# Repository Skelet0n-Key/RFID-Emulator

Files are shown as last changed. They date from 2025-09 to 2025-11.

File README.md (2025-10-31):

# Project Overview

**Introduction**

The standard PN532 is widely available and cheap. Manufacturers prevent custom UIDs from being emulated. When the 532 is put into target mode, the first byte of the UID will always be 0x08 (or 0x88 with some models). While there are ways to get around this security feature, it is difficult to implement in an embedded system, unreliable, and requires perfect timing (read more about it [here](https://www.mankier.com/1/nfc-emulate-uid)). The other solution is trivially easy to implement. Rather than go with the true emulation method, we picked up a [lab401 sector 0 programmable card](https://lab401.com/collections/all-products/products/mifare-compatible-1k-direct-write-uid). This method absolves adafruit of all legal liability, which is exactly the reason that firmware feature implementing a hardware protocol requirement (prepending a 0x08 byte) exists. Conveniently, this makes our design more discreet. 

**Challenges and Solutions**

- We wanted a controlled environment to test our project's functionality and so that's what we did. We made an RFID lock with an arduino uno and MFRC-522 module (code found [here](RFID_lock/RFID_lock.ino)). The lock came with it's own problems. It took a while to find out what was going on, but we weren't getting any response from our MFRC-522 because it wasn't an official module. We needed to slow down communication to our module and connect it to 5V even though 3.3V was printed on the PCB. *Note: we labeled it 3.3V-3.3V in the wiring diagram*
- The original idea for this project was to have the PN532 emulate the copied UID itself. Unfortunately, due to security concerns (😒) the PN532 prepends a 0x08 byte when it sends its UID. So calling the command to send a specified UID like: 0x0000BEEF, would send: 0x080000BE. Luckily, you can just write a non-modified UID to a card. So this is what we ended up pivoting to as you read above.

**Timeline**

- Test lock finished (9/26/25)
- Basic read functions implemented on PN532 (10/7/25)
- Emulating function implemented, it is discovered that an 0x08 is prepended to every emulation (10/16/25)
- Writing function finished (10/23/25)
- Functional prototype finished (10/27/25)
- Rev1 finsihed with screen displaying selectable UIDs to write. UIDs saved in memory ()
- NFC compatibility added ()
- wifi de-auther added ()
- 125kHz module added ()

**Testing and Results**

# Project Capabilities

# Hardware Components

 - Raspberry Pi Pico 2 W
 - Adafruit PN532
 - *Arduino UNO
 - *RFID-MFRC522 module

*Necessary for RFID test lock

# Software Dependencies

 - [micropython .UF2 for pi pico 2 W](https://www.raspberrypi.com/documentation/microcontrollers/micropython.html)
 - [NFC PN532 SPI library](https://github.com/Carglglz/NFC_PN532_SPI?tab=readme-ov-file)
 - *[MFRC library](https://docs.arduino.cc/libraries/mfrc522)

*Necessary for RFID test lock

# Implementation

## Wiring Diagrams and Information

**Emulator**
*Diagram Here*

| RPI Pico 2 W | Adafruit PN532 Breakout |
|:---|:---|
| 3V3 (3.3V) | Vcc / 3.3V |
| GND | GND |
| GP16 (SPI0 MISO) | MISO (SSO / SO) |
| GP17 (CS / CHIP_SELECT | SS (active low) |
| GP18 (SPI0 SCK) | SCK |
| GP19 (SPI0 MOSI) | MOSI (SDA) |
| (optional) GP15 | IRQ |
| (optional) GP20 | RSTO / RST |

**RFID Lock**
*Diagram Here*

| Arduino Uno | MFRC-522 |
|:----|:----|
| 3.3V | 3.3V |
| GND | GND |
| D9 | RST |
| D10 | SDA |
| D11 | MOSI |
| D12 | MISO |
| D13 | SCK |
| N/A | IRQ |

We also used two indicator LEDs on D2 and D4 so we didn't have to look at the terminal everytime to see if access was granted / denied. 

## CAD Files

We used a few prints to bring this project together and give it a more prolished look. You can find them [here]()
(link)

# Acknowledgements
We used Carglglz's [driver](https://github.com/Carglglz/NFC_PN532_SPI) to control the basic functions of the PN532, such as initialization and reading mifare classics.

We added functionality to that driver using the principles from the [Adafruit PN532 driver](https://github.com/adafruit/Adafruit-PN532/blob/master/Adafruit_PN532.cpp) to write data to a programmable card, following mifare classic protocol.

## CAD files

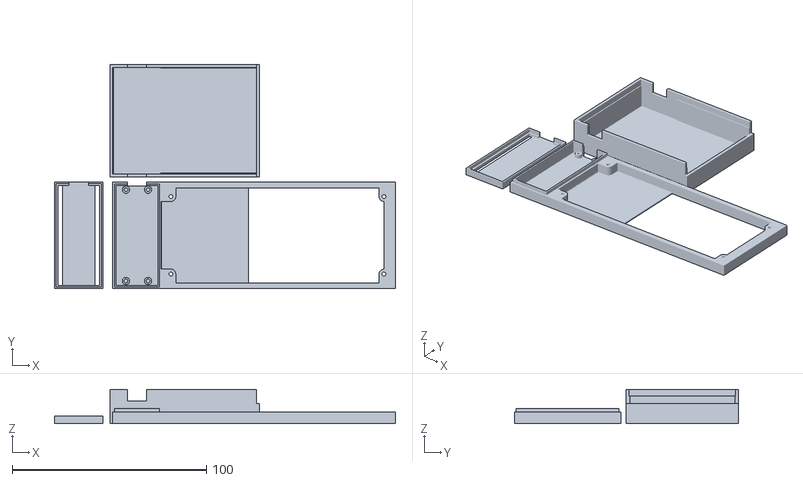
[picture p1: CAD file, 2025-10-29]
Cad_files/case v8.stl
175.6 x 115.6 x 17.7

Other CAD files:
Cad_files/case v8.f3d

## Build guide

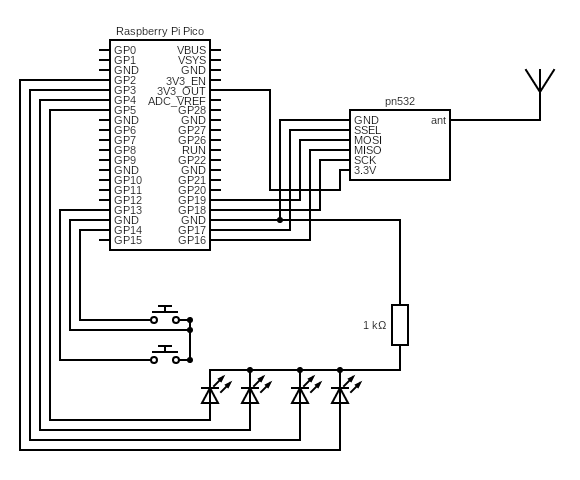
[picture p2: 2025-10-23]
Wiring_diagrams/circuit.png

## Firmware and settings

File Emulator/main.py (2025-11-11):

from machine import Pin, SPI, I2C
import NFC_PN532 as nfc
from ssd1306 import SSD1306_I2C
import time
import ujson
import os

# ==== I2C setup ====
i2c = I2C(1, scl=Pin(3), sda=Pin(2))  # I2C1 uses GP2 (SDA) and GP3 (SCL)

# ==== OLED setup ====
WIDTH = 128
HEIGHT = 32  # most 0.91" displays are 128x32
oled = SSD1306_I2C(WIDTH, HEIGHT, i2c)

# --- NFC/SPI Setup ---
spi = SPI(0,
          baudrate=1152000,
          polarity=0,
          phase=0,
          bits=8,
          firstbit=SPI.MSB,
          sck=Pin(18),
          mosi=Pin(19),
          miso=Pin(16))

cs = Pin(17, Pin.OUT)
cs.value(1)
rst = Pin(20, Pin.OUT)
rst.value(1)
# IRQ pin is not used in this library's polling mode
# irq = Pin(15, Pin.IN) 
irq = None # Set to None
# Initialize GPIO pins for the buttons.
# We are using internal pull-ups, so the buttons should be wired
# to connect the pin to ground when pressed.
up_button = Pin(14, Pin.IN, Pin.PULL_UP)
sel_button = Pin(13, Pin.IN, Pin.PULL_UP)
down_button = Pin(5, Pin.IN, Pin.PULL_UP)


# menus
mainMenu = [" ", "Mifare Classic", "NTAG", "Clear Saved", " "]
mifareMenu = [" ", "..", "Mifare Read", "Write current", "Save current", "Load from saved", " "]
ntagMenu = [" ", "..", "NTAG read", "Write current", "Save current", "Load from saved", " "]

# saved data
MIFARE_FILE = "saved_mifare.json"
NTAG_FILE = "saved_ntag.json"
savedUIDsMifare = []
savedUIDsNTAG = []
saved_block_0 = None

# --- PN532 Initialization ---
print("Initializing PN532...")
pn532 = nfc.PN532(spi, cs, rst, irq)
ic, ver, rev, support = pn532.get_firmware_version()
print('Found PN532 with firmware version: {}.{}'.format(ver, rev))
pn532.SAM_configuration()

# initialize screen and menu
currentMenu = mainMenu
currentOptionIndex = 1
driverSelection = None

def calculate_bcc(uid_bytes):
    """
    Calculates the BCC (XOR checksum) for a 4-byte MIFARE UID.
    """
    if len(uid_bytes) != 4:
        raise ValueError("UID must be 4 bytes long")
    bcc = 0
    for byte in uid_bytes:
        bcc ^= byte
    return bcc


def read_source_card_data(dev, timeout_ms=5000):
    """
    Waits for a source card, authenticates block 0, validates its BCC, 
    and reads the 16-byte block.
    Returns the 16 bytes of block 0, or None if it fails.
    """
    print('Waiting for SOURCE card...')
    oled_print("Waiting for SOURCE card...", clear=True)
    print('Present the card you want to CLONE.')
    start = time.ticks_ms()
    uid = None
    while time.ticks_diff(time.ticks_ms(), start) < timeout_ms:
        # Check for a card
        uid = dev.read_passive_target(timeout=100)
        if uid is not None:
            # Card found, break out of the loop
            break
        time.sleep(0.1)

    if not uid:
        print('CARD NOT FOUND')
        oled_print("CARD NOT FOUND", clear=True)
        return None
        
    uid_string = "".join(["{:02X}".format(i) for i in uid])
    print(f"Found source card with UID: {uid_string}")
    oled_print(f"Found:\n{uid_string}", clear=True)

    # Authenticate block 0 (or any block in sector 0) to read it.
    # We'll try a common default key, KEY_DEFAULT_B (all 0xFFs)
    print("Trying to authenticate with default key FF FF FF FF FF FF...")
    oled_print("Authenticating\nsource card...", clear=False)
    if not dev.mifare_classic_authenticate_block(uid, 0, nfc.MIFARE_CMD_AUTH_B, nfc.KEY_DEFAULT_B):
        print("Failed to authenticate block 0 with default key.")
        print("Note: Card must use the default key FF FF FF FF FF FF for this to work.")
        oled_print("Authentication\nfailed!", clear=True)
        return None
    
    print("Authentication successful.")
    oled_print("Authentication\nsuccessful!", clear=True)
    
    # Read block 0
    block0_data = dev.mifare_classic_read_block(0)
    
    if not block0_data:
        print("Failed to read block 0.")
        oled_print("Read Block 0\nfailed!", clear=True)
        time.sleep(1)
        return None

    print(f"Successfully read Block 0: {[hex(b) for b in block0_data]}")
    oled_print("Read Block 0\nsuccessful!", clear=True)
    time.sleep(1)

    # --- BCC SAFETY CHECK ---
    print("Validating source card BCC...")
    oled_print("Validating\nsource card BCC...", clear=True)
    card_uid_part = block0_data[0:4]
    card_bcc_part = block0_data[4]
    
    calculated_bcc = calculate_bcc(card_uid_part)
    
    if card_bcc_part == calculated_bcc:
        print(f"BCC is valid! (Read: 0x{card_bcc_part:02X}, Calculated: 0x{calculated_bcc:02X})")
        oled_print("BCC VALIDATION\nSUCCESS!", clear=True)
        time.sleep(0.5)
        oled_print("Block 0 Data:\n" + "".join(["{:02X}".format(b) for b in block0_data]), clear=True)
        time.sleep(3)
        return block0_data
    else:
        print("--- !!! BCC VALIDATION FAILED !!! ---")
        oled_print("!!! BCC VALIDATION\nFAILED !!!", clear=True)
        print(f"Read UID: {[hex(b) for b in card_uid_part]}")
        print(f"Read BCC: 0x{card_bcc_part:02X}")
        print(f"Calculated BCC: 0x{calculated_bcc:02X}")
        print("This card may be damaged or non-standard. Aborting clone to prevent bricking.")
        time.sleep(0.5)
        return None
    # --- END OF BCC CHECK ---


def write_data_to_clone(dev, block_data, timeout_ms=10000):
    """
    Waits for a programmable card and writes the saved block 0 data to it.
    This requires a special UID-modifiable card.
    """
    print("Waiting for TARGET card...")
    oled_print("Waiting for TARGET card...", clear=True)
    print("Present your UID-MODIFIABLE (magic) card.")

    # Wait for a target card to appear
    start_wait = time.ticks_ms()
    target_uid = None
    while time.ticks_diff(time.ticks_ms(), start_wait) < timeout_ms:
        target_uid = dev.read_passive_target(timeout=100)
        if target_uid is not None:
            break
        time.sleep(0.1)

    if not target_uid:
        print("No target card found to write to. Aborting.")
        oled_print("No target card found.\nAborting.", clear=True)
        return

    target_uid_string = "".join(["{:02X}".format(i) for i in target_uid])
    print(f"Found target card with UID: {target_uid_string}")
    oled_print(f"Found target card:\n{target_uid_string}", clear=True)

    # For "Gen2" or "lab 401" cards, we can try a normal authentication
    # and then a standard write command to block 0.
    
    print("Attempting to authenticate target card...")
    # authenticate with the card's current key.
    # For a blank/new magic card, this is often the default key.
    if not dev.mifare_classic_authenticate_block(target_uid, 0, nfc.MIFARE_CMD_AUTH_B, nfc.KEY_DEFAULT_B):
        print("Failed to authenticate target card with default key.")
        oled_print("Authentication\nfailed!", clear=True)
        time.sleep(1.5)
        return
        
    print("Target card authenticated. Attempting to write to Block 0...")
    oled_print("Writing to\nBlock 0...", clear=True)
    
    # Now, try to write the saved block 0 data
    if dev.mifare_classic_write_block(0, block_data):
        print("SUCCESS! Block 0 written.")
        oled_print("Write SUCCESS!", clear=True)
        print(f"Wrote data: {[hex(b) for b in block_data]}")
        oled_print(f"Wrote data:\n{''.join(['{:02X}'.format(b) for b in block_data])}", clear=True)
        time.sleep(1.5)
        return
    else:
        print("Error: Failed to write to block 0.")
        oled_print("Write FAILED!", clear=True)
        time.sleep(1.5) 
        return


def driver_select(selection):
    global saved_block_0
    if selection == 0: #scan mifare classic
        scanned_data = read_source_card_data(pn532)
    
        if scanned_data:
            saved_block_0 = scanned_data # Save the 16-byte block
            print("Block 0 data saved.")
            oled_print("Scan successful!\nData saved.", clear=True)
            time.sleep(1.5)
        else:
            print("Scan failed. No data was saved.")
            oled_print("Scan failed.\nNo data saved.", clear=True)  
            time.sleep(1.5)

    elif selection == 1:#write mifare classic
        print("Writing saved Block 0 data to target card...")
        if saved_block_0 is None:
            print("Error: No data has been saved from a source card.")
            oled_print("No saved data!\nScan first.", clear=True)
            time.sleep(1.5)
        else:
            data_string = "".join(["{:02X}".format(i) for i in saved_block_0])
            print(f"Writing data: {data_string}")
            oled_print(f"Writing data:\n{data_string}", clear=True)
            write_data_to_clone(pn532, saved_block_0)

    elif selection == 2: #save current mifare classic TODO
        oled_print("Saving current\nMIFARE UID...", clear=True)
        time.sleep(0.5)
        savedUIDsMifare.append(saved_block_0)
        save_list_to_file(savedUIDsMifare, MIFARE_FILE) 

    elif selection== 3: #display saved mifare classic uids TODO
        oled_print("Loading saved\nMIFARE UIDs...", clear=True)
        time.sleep(0.5)
        savedUIDsMifare = load_list_from_file(MIFARE_FILE)
        for index, data in enumerate(savedUIDsMifare):
            data_string = "".join(["{:02X}".format(b) for b in data])
            print(f"{index + 1}: {data_string}")
            oled_print(f"{index + 1}: {data_string}")

    elif selection == 4: 
        oled_print("NTAG read not\nimplemented", clear=True)
        time.sleep(1.5)

        
    elif selection == 5: 
        oled_print("NTAG write not\nimplemented", clear=True)
        time.sleep(1.5)

    elif selection == 6: 
        oled_print("Save current to\nNTAG list not\nimplemented", clear=True)
        time.sleep(1.5)

    elif selection == 7: 
        oled_print("Display saved\nNTAG UIDs not\nimplemented", clear=True)
        time.sleep(1.5)

    else: pass  # no action

# --- Save function ---
def save_list_to_file(data_list, filename):
    try:
        with open(filename, "w") as f:
            ujson.dump(data_list, f)
        print(f"Saved {len(data_list)} items to {filename}")
        oled_print(f"Saved {len(data_list)} items", clear=True)
    except Exception as e:
        print("Error saving file:", e)
        oled_print("Error saving file", clear=True)
    
    return

# --- Load function ---
def load_list_from_file(filename):
    try:
        with open(filename, "r") as f:
            data = ujson.load(f)
        print(f"Loaded {len(data)} items from {filename}")
        return data
    except Exception as e:
        print("Error loading file:", e)
        oled_print("Error loading file", clear=True)
        return []
    
# --- Clear saved function ---    
def clear_saved_list(list_variable, filename):
    # Clear the in-memory list
    list_variable.clear()
    
    # Overwrite the JSON file with an empty list
    try:
        with open(filename, "w") as f:
            ujson.dump([], f)
        print(f"Cleared {filename} and emptied the list.")
        oled_print(f"Cleared saved\nitems!", clear=True)
    except Exception as e:
        print("Error clearing saved file:", e)
        oled_print("Error clearing\nsaved items!", clear=True)

def oled_print(*args, sep=" ", end="\n", clear=True):
    """
    Works like Python's print(), but writes to the OLED display.
    Example: oled_print("Hello", 123)
    """
    text = sep.join(str(a) for a in args) + end

    if clear:
        oled.fill(0)  # clear screen

    # split into lines and display
    lines = text.splitlines()
    y = 0
    for line in lines:
        if y > HEIGHT - 8:
            break  # stop if screen full
        oled.text(line[:21], 0, y)  # each char ≈6px wide → fits ~21 chars
        y += 8

    oled.show()

def printMenu(menu, index):
    # Clamp the index inside valid range
    if index <= 0:
        index = 1
    if index >= len(menu) - 1:
        index = len(menu) - 2

    ln1 = menu[index - 1]
    ln2 = menu[index]
    ln3 = menu[index + 1]

    text = f"{ln1}\n>{ln2}\n{ln3}"
    oled_print(text, clear=True)

    return index

# initialize
currentMenu = mainMenu
currentOptionIndex = 1
driverSelection = None

printMenu(currentMenu, currentOptionIndex)

while True:

    if up_button.value() == 0:  # up
        time.sleep(0.2)  # Debounce delay
        if currentOptionIndex > 1:
            currentOptionIndex -= 1
        currentOptionIndex = printMenu(currentMenu, currentOptionIndex)

    elif down_button.value() == 0:  # down
        time.sleep(0.2)  # Debounce delay
        if currentOptionIndex < len(currentMenu) - 2:
            currentOptionIndex += 1
        currentOptionIndex = printMenu(currentMenu, currentOptionIndex)

    elif sel_button.value() == 0:  # select
        time.sleep(0.2)  # Debounce delay
        if currentMenu == mainMenu:
            if currentOptionIndex == 1:  # Mifare Classic
                currentMenu = mifareMenu
                currentOptionIndex = 2
            elif currentOptionIndex == 2:  # NTAG
                currentMenu = ntagMenu
                currentOptionIndex = 2
            elif currentOptionIndex == 3:  # Clear Saved
                clear_saved_list(savedUIDsMifare, MIFARE_FILE)
                clear_saved_list(savedUIDsNTAG, NTAG_FILE)
            currentOptionIndex = printMenu(currentMenu, currentOptionIndex)

        elif currentMenu == mifareMenu:
            if currentOptionIndex == 1:  # go back
                currentMenu = mainMenu
                currentOptionIndex = 1
                driverSelection = None
            elif currentOptionIndex == 2:
                driverSelection = 0
            elif currentOptionIndex == 3:
                driverSelection = 1
            elif currentOptionIndex == 4:
                driverSelection = 2
            elif currentOptionIndex == 5:
                driverSelection = 3
            if driverSelection is not None:
                driver_select(driverSelection)
                driverSelection = None
            currentOptionIndex = printMenu(currentMenu, currentOptionIndex)

        elif currentMenu == ntagMenu:
            if currentOptionIndex == 1: #go back
                currentMenu = mainMenu
                currentOptionIndex = 1
                driverSelection = None
            elif currentOptionIndex == 2:
                driverSelection = 4
            elif currentOptionIndex == 3:
                driverSelection = 5
            elif currentOptionIndex == 4:
                driverSelection = 6
            elif currentOptionIndex == 5:
                driverSelection = 7
            if driverSelection is not None:
                driver_select(driverSelection)
                driverSelection = None
            currentOptionIndex = printMenu(currentMenu, currentOptionIndex)

    else:
        # invalid key
        pass

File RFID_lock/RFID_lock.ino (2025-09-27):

// ** REFER TO THE README AT https://github.com/megabyte512/RFID-Emulator FOR WIRING INSTRUCTIONS **

#include <MFRC522.h>
#include <SPI.h>

#define SS_PIN 10
#define RST_PIN 9

MFRC522 RFID_lock(SS_PIN, RST_PIN);
int GREEN_LED_PIN = 2;
int RED_LED_PIN = 4;

void handleSerialCommands();
void addCardMode();
void removeCardMode();
void checkForCard();
void listAuthorizedCards();
void clearAllCards();
String getCardUID();
bool isCardAuthorized(String cardUID);
bool removeCard(String cardUID);

String authorizedCards[10];
int cardCount = 0;


void setup() {
  Serial.begin(9600);
  SPI.begin();
  SPI.setClockDivider(SPI_CLOCK_DIV128); // Our specific clone fix :(
  RFID_lock.PCD_Init();
  pinMode(GREEN_LED_PIN, OUTPUT);
  pinMode(RED_LED_PIN, OUTPUT);

  Serial.println("***RFID Access Control System***");
  Serial.println("- ADD: Add a new card");
  Serial.println("- LIST: Show all authorized cards");
  Serial.println("- CLEAR: Remove all cards");
  Serial.println("- REMOVE: Remove specific card");
  Serial.println();
}



void loop() {
  handleSerialCommands();
  checkForCard();
  delay(100);
}


void handleSerialCommands() {
  if (Serial.available()) {
    String command = Serial.readStringUntil('\n');
    command.trim();
    command.toUpperCase();
    
    if (command == "ADD") {
      addCardMode();
    }
    else if (command == "LIST") {
      listAuthorizedCards();
    }
    else if (command == "CLEAR") {
      clearAllCards();
    }
    else if (command == "REMOVE") {
      removeCardMode();
    }
    else {
      Serial.println("Unknown command: " + command);
    }
  }
}


void addCardMode() {
  if (cardCount >= 10) {
    Serial.println("Maximum cards reached (10)");
    return;
  }
  
  Serial.println("Listening for card...");
  
  unsigned long timeout = millis() + 10000;  // 10 second timeout
  
  while (millis() < timeout) {
    // Check for card
    if (RFID_lock.PICC_IsNewCardPresent() && RFID_lock.PICC_ReadCardSerial()) {
      String newCardUID = getCardUID();
      
      // Check if card already exists
      if (isCardAuthorized(newCardUID)) {
        Serial.println("Card already in authorized list: " + newCardUID);
      } else {
        // Add new card
        authorizedCards[cardCount] = newCardUID;
        cardCount++;
        Serial.println("Card added successfully: " + newCardUID);
        Serial.println("Total authorized cards: " + String(cardCount));
      }
      return;
    }
  }
  
  Serial.println("Add timeout - no card presented");
}


void removeCardMode() {
  if (cardCount == 0) {
    Serial.println("No cards to remove");
    return;
  }
  
  Serial.println("Listening for card to remove...");
  
  unsigned long timeout = millis() + 10000;
    while (millis() < timeout) {
      if (RFID_lock.PICC_IsNewCardPresent() && RFID_lock.PICC_ReadCardSerial()) {
        String cardUID = getCardUID();
      
        if (removeCard(cardUID)) {
          Serial.println("Card removed: " + cardUID);
          Serial.println("Total authorized cards: " + String(cardCount));
        } else {
          Serial.println("Card not found in authorized list: " + cardUID);
        }
        return;
      }
    }
  Serial.println("Remove timeout - no card presented");
}


void checkForCard() {
  if (RFID_lock.PICC_IsNewCardPresent() && RFID_lock.PICC_ReadCardSerial()) {
    String cardUID = getCardUID();
    
    if (isCardAuthorized(cardUID)) {
      Serial.println("ACCESS GRANTED: " + cardUID);
      digitalWrite(GREEN_LED_PIN, 1);
      delay(1000);
      digitalWrite(GREEN_LED_PIN, 0);
    } else {
      Serial.println("ACCESS DENIED: " + cardUID);
      digitalWrite(RED_LED_PIN, 1);
      delay(1000);
      digitalWrite(RED_LED_PIN, 0);
    }
    return;
  }
}


String getCardUID() {
  String content = "";
  for (byte i = 0; i < RFID_lock.uid.size; i++) {
    content.concat(String(RFID_lock.uid.uidByte[i] < 16 ? "0" : ""));
    content.concat(String(RFID_lock.uid.uidByte[i], HEX));
  }
  content.toUpperCase();
  return content;
}


bool isCardAuthorized(String cardUID) {
  for (int i = 0; i < cardCount; i++) {
    if (authorizedCards[i] == cardUID) {
      return true;
    }
  }
  return false;
}


bool removeCard(String cardUID) {
  for (int i = 0; i < cardCount; i++) {
    if (authorizedCards[i] == cardUID) {
      // Shift remaining cards down
      for (int j = i; j < cardCount - 1; j++) {
        authorizedCards[j] = authorizedCards[j + 1];
      }
      cardCount--;
      return true;
    }
  }
  return false;
}


void listAuthorizedCards() {
  Serial.println("=== Authorized Cards ===");
  if (cardCount == 0) {
    Serial.println("No authorized cards");
  } else {
    for (int i = 0; i < cardCount; i++) {
      Serial.println(String(i + 1) + ". " + authorizedCards[i]);
    }
  }
  Serial.println("Total: " + String(cardCount) + "/10");
}


void clearAllCards() {
  cardCount = 0;
  Serial.println("All authorized cards removed");
}

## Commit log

2025-09-27 Create README.md
    Started README
    Started wiring description for RFID lock
2025-10-16 added delays to allow the PN532 to power up. added while loop to continue to run program rather than exit upon reading a card
2025-10-23 added link to pn532 driver
2025-10-23 current working program
2025-10-23 changed output, started on the LED indicators
2025-10-23 implemented full functioning LED indicators
2025-10-23 wiring diagrams
2025-10-25 Update README.md
    Forgot to put CAD files as a subsection under implementation.
2025-10-25 Created directory for CAD files. removed screenshot of wiring labels
2025-10-29 cad files for case
    [case v8.f3d, case v8.stl]
2025-10-29 arduino stepper test
2025-10-30 Revised introduction
    Also formatted a bit, linked website, added a couple of goals we can shoot for
